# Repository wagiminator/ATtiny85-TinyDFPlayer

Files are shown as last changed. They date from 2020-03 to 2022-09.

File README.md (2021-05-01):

# TinyDFPlayer - MP3-Player based on ATtiny85 and DFPlayerMini
ATtiny controlled and LiPo battery powered MP3-Player using the DFPlayerMini module featuring:
- Micro-SD-card slot
- Battery charging and protection circuit
- Battery level detection
- OLED display
- On/off switch
- Volume control
- Three push buttons to control the player
- Remembers the last track played after switching off (EEPROM)

You can directly connect a 3.7 V Li-Po battery and a 3 W / 4 Ohm speaker to the board.

- Project Video (YouTube): https://youtu.be/QYjr8UXhs8I
- Design Files (EasyEDA): https://easyeda.com/wagiminator/attiny85-tinydfplayer-smd

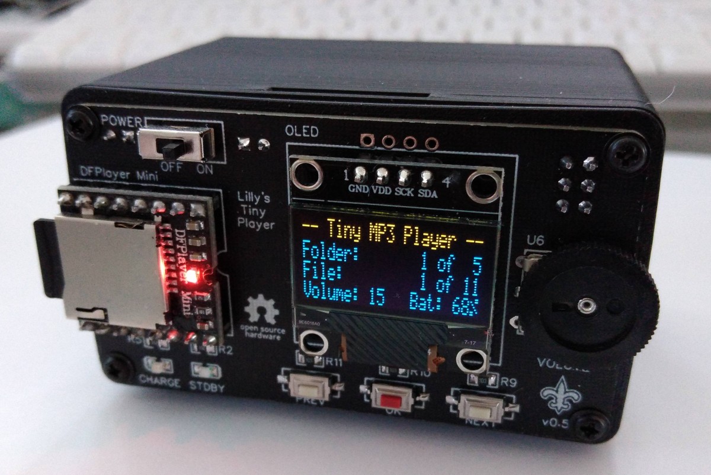
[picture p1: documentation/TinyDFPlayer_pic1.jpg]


# Hardware
## DFPlayer Mini Module
The [DFPLayer Mini module](https://wiki.dfrobot.com/DFPlayer_Mini_SKU_DFR0299) is a serial MP3 module that offers the perfect built-in MP3 hardware decoding. It supports TF cards with FAT16 and FAT32 file systems. Music playback as well as other functions can be controlled by simple serial commands without cumbersome software implementation. The main features of the module are easy to use, stable and reliable functions.

## Battery Charger
For battery charging the [TP4056](https://datasheet.lcsc.com/szlcsc/1904031009_TPOWER-TP4056_C382139.pdf) is used. The TP4056 is a complete constant-current/constant-voltage linear charger for single cell lithium-ion batteries. The charge voltage is fixed at 4.2V and the charge current (max 1000mA) can be programmed externally with a single resistor (R6). The TP4056 automatically terminates the charge cycle when the charge current drops to 1/10th the programmed value after the final float voltage is reached. Other features include current monitor, under voltage lockout and automatic recharge. Charging is done via the built-in [Micro USB connector](https://aliexpress.com/wholesale?SearchText=micro+usb+2pin+dip).

## Battery Protection
For the battery protection (overcharge, overdischarge, overcurrent and short circuit protection) the [DW01A](https://datasheet.lcsc.com/szlcsc/1901091236_PUOLOP-DW01A_C351410.pdf) is used in combination with an [FS8205](https://datasheet.lcsc.com/szlcsc/Fortune-Semicon-FS8205_C32254.pdf) dual MOSFET. The DW01A is constantly measuring the voltage across the battery and the current flowing in (when charging) or coming out (when discharging). If something goes wrong it takes the battery out of the circuit by closing the MOSFET which acts like a switch between the negative side of the battery (B-) and ground. The overcurrent protection works by comparing the voltage drop across the MOSFET with the internal 150mV reference of the DW01A. As the RDS(on) of one FS8205 is around 2x25mOhm, the DW01A will close the MOSFET at 150mV/50mOhm = 3A.

## User Interface
The user interface utilizes three buttons, a wheel potentiometer and a [128x64 pixels OLED display](http://aliexpress.com/wholesale?SearchText=128+64+0.96+oled+new+4pin). An [ATtiny85](https://ww1.microchip.com/downloads/en/DeviceDoc/Atmel-2586-AVR-8-bit-Microcontroller-ATtiny25-ATtiny45-ATtiny85_Datasheet.pdf) microcontroller brings it all together.

# Building Instructions
## Calibrating ATtiny85's Internal Oscillator
Error-free serial communication with the DFPlayer module requires precise timing. Usually the internal oscillator of the ATtiny85 used for this is sufficiently accurate (at least I haven't had any problems so far). However, the serial communication may not work due to an imprecise oscillator. It is therefore recommended to calibrate it manually. There are numerous instructions on how to do this on the [Internet](http://ernstc.dk/arduino/tinytuner.html). Alternatively, the [TinyICOC](https://github.com/wagiminator/ATtiny84-TinyICOC) or the [TinyCalibrator](https://github.com/wagiminator/ATtiny84-TinyCalibrator) can be used for this.

## Building the TinyDFPlayer
Solder all of the components onto the circuit board. Connect a 3.7 V Li-Po battery and a 3 W / 4 Ohm speaker to the corresponding pin headers.

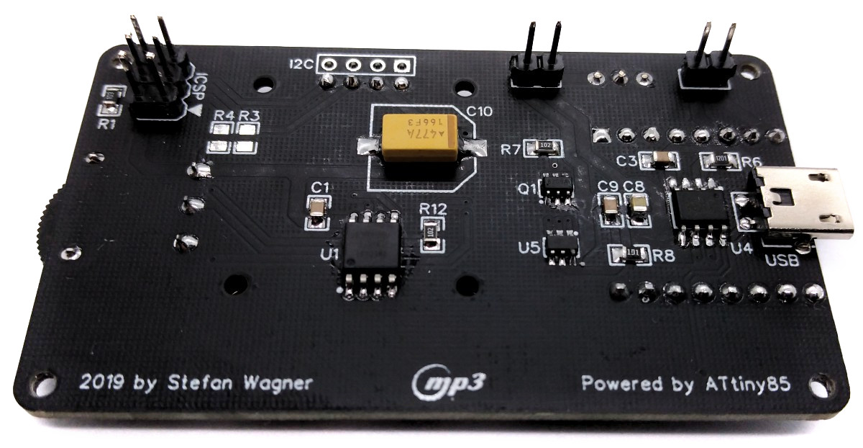
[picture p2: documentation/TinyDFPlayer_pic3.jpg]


If you want to use the 3D-printed case, first install a [70 * 40 mm speaker](https://aliexpress.com/wholesale?SearchText=speaker+4070) in the lower part of the housing and screw it in with 2.3 * 5 mm self-tapping screws. Place an approx. 1 cm thick piece of foam behind the speaker, which fits tightly against the outer walls of the housing. This improves the sound quality significantly and separates the battery from the speaker. Then place the battery. Click the upper part of the housing on the lower part and screw on the TinyDFPlayer Board with 2.3 * 5 mm self-tapping screws. Glue four rubber feet to the underside of the player.

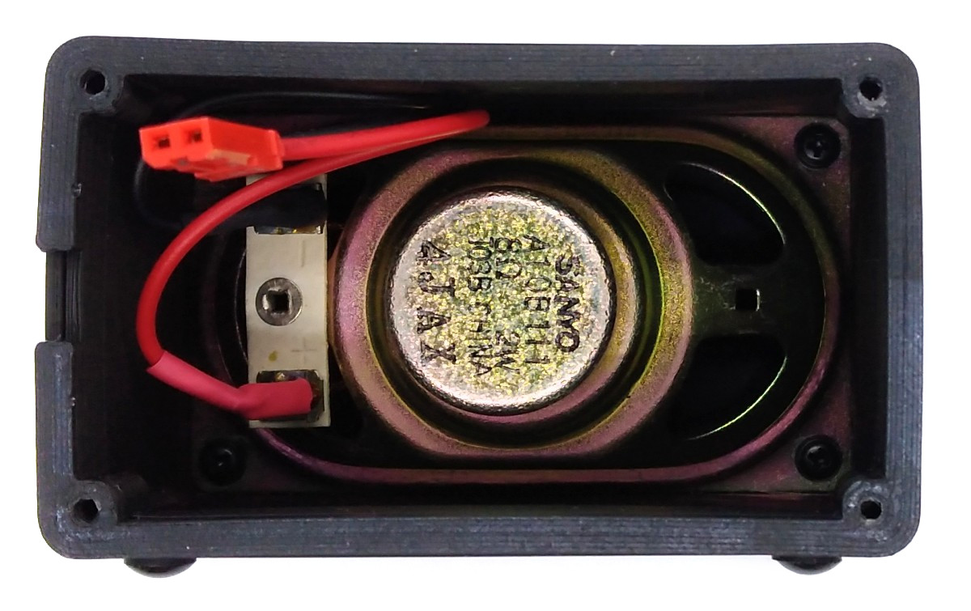
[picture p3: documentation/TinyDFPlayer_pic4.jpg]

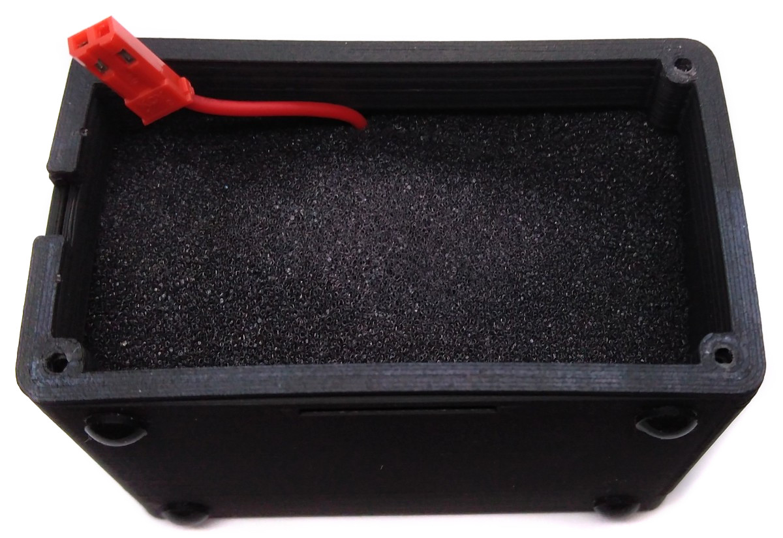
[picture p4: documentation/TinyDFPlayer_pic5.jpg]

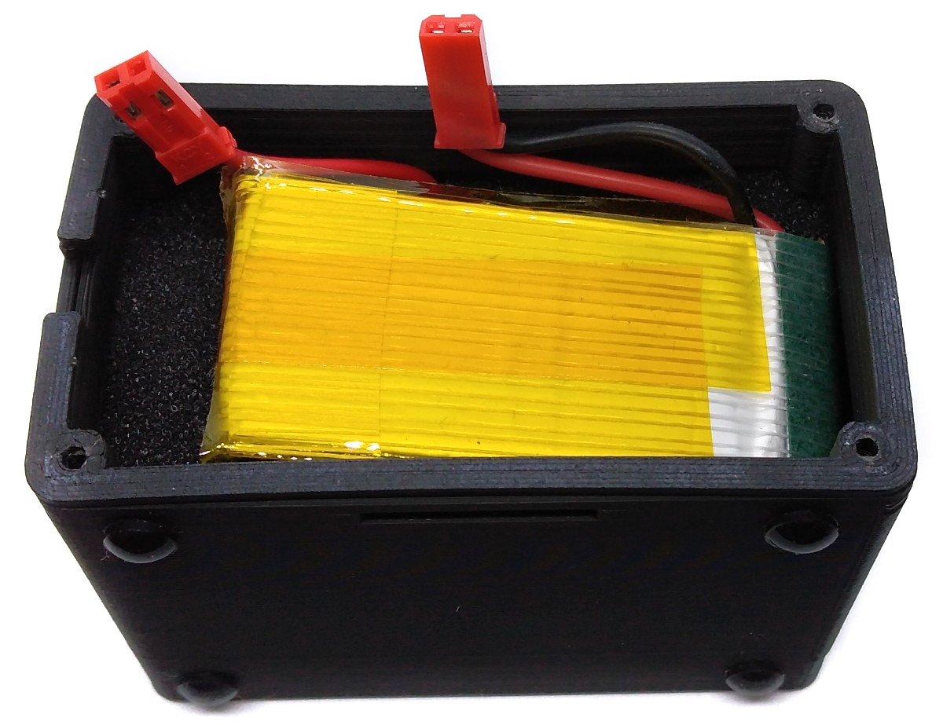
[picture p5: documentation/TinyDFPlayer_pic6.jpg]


## Compiling and Uploading the Software
### If using the Arduino IDE
- Make sure you have installed the following core and libraries: 
  - [ATtinyCore](https://github.com/SpenceKonde/ATTinyCore)
  - [TinyI2CMaster](https://github.com/technoblogy/tiny-i2c)
  - [Tiny4kOLED](https://github.com/datacute/Tiny4kOLED)
  - [DFRobotDFPlayerMini](https://github.com/DFRobot/DFRobotDFPlayerMini)
- Go to **Tools -> Board -> ATtinyCore** and select **ATtiny25/45/85 (No bootloader)**.
- Go to **Tools** and choose the following board options:
  - **Chip:**           ATtiny85
  - **Clock:**          8 MHz (internal)
  - Leave the rest at the default settings
- Connect your programmer to your PC and to the ICSP header of the device.
- Go to **Tools -> Programmer** and select your ISP programmer (e.g. [USBasp](https://aliexpress.com/wholesale?SearchText=usbasp)).
- Go to **Tools -> Burn Bootloader** to burn the fuses.
- Open TinyDFPlayer sketch and click **Upload**.

### If using the precompiled hex-file
- Make sure you have installed [avrdude](https://learn.adafruit.com/usbtinyisp/avrdude).
- Connect your programmer to your PC and to the ICSP header of the device.
- Open a terminal.
- Navigate to the folder with the hex-file.
- Execute the following command (if necessary replace "usbasp" with the programmer you use):
  ```
  avrdude -c usbasp -p t85 -U lfuse:w:0xe2:m -U hfuse:w:0xd7:m -U efuse:w:0xff:m -U flash:w:tinyDFPlayer_v1.2.hex
  ```

# Operating Instructions
## Preparing the SD-Card
Micro SD cards (TF cards) with a maximum of 32 GB are supported. The card should be formatted in the FAT32 file system. The firmware is written for the folder-play function of the DFPlayer. This means you have to create folders named 01, 02, 03, ... in the  SD card root and inside the folders you have to name the audio files 001.mp3, 002.mp3, ... The maximum number of folders is 99 and the maximum number of files per folder is 255. Don't leave gaps in the folders or file numbers. After the three-digit number of the MP3 files, the title name can be added for better identification, e.g. "003_MySong.mp3". Note that the title names cannot be read out and transmitted by the MiniDFPlayer module, so unfortunately it is not possible to display the title names.

There must not be any unnecessary files on the SD card, such as those stored there by MacOS (e.g. Spotlight). Better take Linux or Windows to write to the SD card. Under MacOS you can try to clean up with the following command:

```
$ dot_clean /Volumes/SD-Card
```

Insert the SD card into the corresponding slot of the DFPlayer Mini module.

## Operating the TinyDFPlayer
The device is switched on with the power switch. The two outer buttons are used to switch files and folders. The middle button is used to switch between pause and play. The wheel potentiometer is for choosing the volume. All necessary information is displayed on the OLED. To charge the battery, connect a 5V power supply via the micro USB port.

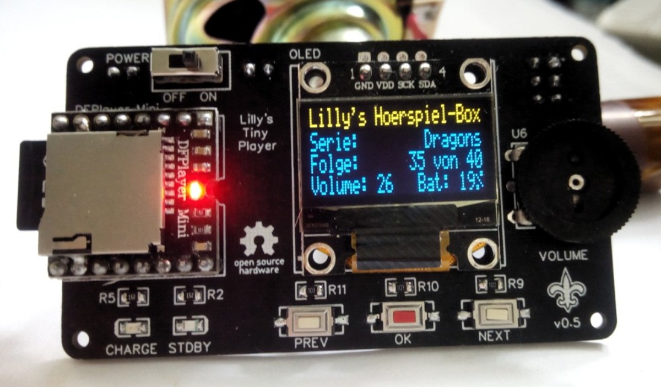
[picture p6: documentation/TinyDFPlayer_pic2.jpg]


# License


This work is licensed under Creative Commons Attribution-ShareAlike 3.0 Unported License. 
(http://creativecommons.org/licenses/by-sa/3.0/)

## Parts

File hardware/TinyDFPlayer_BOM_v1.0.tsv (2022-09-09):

ID | Name | Designator | Footprint | Quantity | Manufacturer Part | Manufacturer | Supplier | Supplier Part
1 | Header | SPK | HDR-1X2/2.54 | 1 | 2.54-1*2PFemale | BOOMELE | LCSC | C49661
2 | Connector | BAT | HDR-1X2/2.54 | 1 | 2.54-1*2PFemale | BOOMELE | LCSC | C49661
3 | DFPlayer | U2 | DFPLAYER_MINI | 1 | ?
4 | 100n | C1,C9,C3 | 805 | 3 | CC0805KRX7R9BB104 | YAGEO | LCSC | C49678
5 | 10u | C8 | 805 | 1 | CL21A106KAYNNNE | SAMSUNG | LCSC | C15850
6 | I2C | I2C | HDR-4X1/2.54 | 1 | Header-Female-2.54_1x4 | ReliaPro | LCSC | C124413
7 | 470uF | C10 | CAP-SMD_D10.0-L10.3-W10.3-H10.2 | 1 | EEE1CA471P | PANASONIC | LCSC | C336217
8 | OLED | OLED | OLED | 1 | ?
9 | ATTINY85-20SU | U1 | SOIC-8_208MIL | 1 | ATTINY85-20SU | MICROCHIP | LCSC | C89852
10 | USB PWR Connector | USB | USB PWR CONNECTOR | 1 | KH-MICRO-SMT.J-2P | Shenzhen Kinghelm Elec | LCSC | C2688799
11 | Slide Switch | POWER | SLIDE SWITCH DPDT 1P2T JB | 1 | New SchematicLib
12 | FS8205 | Q1 | SOT-23-6 | 1 | FS8205 | FORTUNE | LCSC | C32254
13 | ICSP-6 | ICSP | ICSP-6 | 1 | C65114 | BOOMELE | LCSC | C65114
14 | 3x6x2.5 | PREV,NEXT,OK | KEY-3.0*6.0 | 3 | 3x6x2.5Red head high temperature | ReliaPro | LCSC | C46491
15 | 1k | R12,R7 | 805 | 2 | 0805W8F1001T5E | UniOhm | LCSC | C17513
16 | 10k | R11,R10,R1,R9 | 805 | 4 | 0805W8F1002T5E | UniOhm | LCSC | C17414
17 | 4k7 | R4,R3 | 805 | 2 | 0805W8F4701T5E | UniOhm | LCSC | C17673
18 | 1k2 | R6 | 805 | 1 | 0805W8F1201T5E | UniOhm | LCSC | C17379
19 | 1k5 | R5,R2 | 805 | 2 | 0805W8F1501T5E | UniOhm | LCSC | C4310
20 | 100 | R8 | 805 | 1 | 0805W8F1000T5E | UniOhm | LCSC | C17408
21 | DW01A | U5 | SOT-23-6 | 1 | DW01A | FM | LCSC | C85680
22 | 47u | C2 | 1206 | 1 | 1206F476M160NT | FH | LCSC | C30300
23 | Red | L2 | LED-0805 | 1 | 17-21VRD/TR8 | Everlight Elec | LCSC | C264415
24 | Blue | L1 | LED-0805 | 1 | E6C0805QBAC1UDA | EKINGLUX | LCSC | C375453
25 | TP4056 | U4 | SOP-8_EP_150MIL | 1 | TP4056 | TOPPOWER | LCSC | C16581
26 | B103 3 pin | U6 | B103 3 PIN | 1 | ?

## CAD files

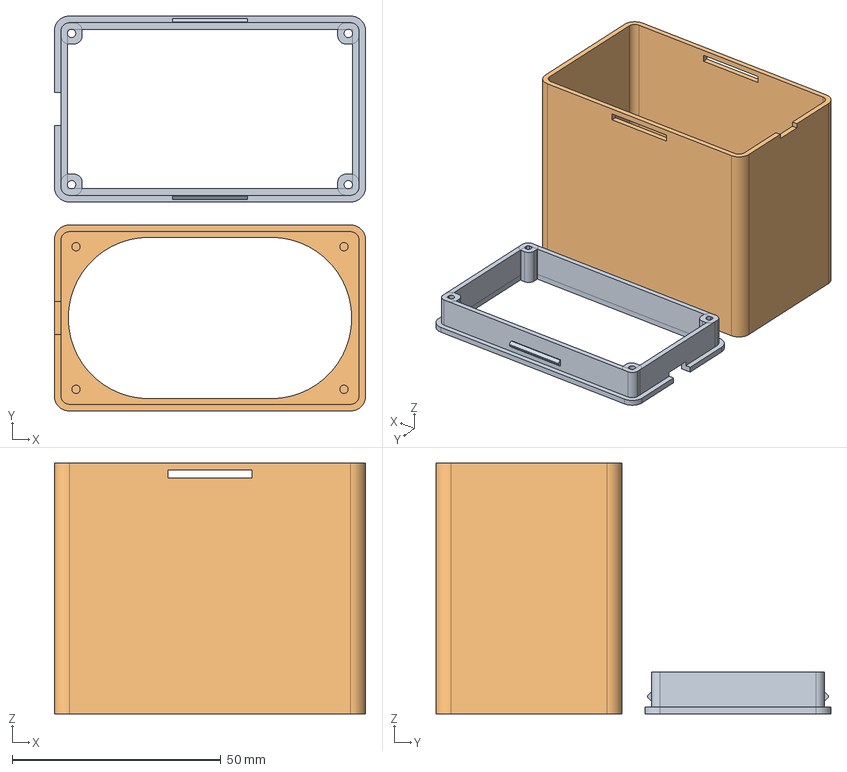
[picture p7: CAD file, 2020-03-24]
3dprint/TinyDFplayer2.fcstd
74.5 x 94.5 x 60.0 mm
Boardhalter
Speakerhalter

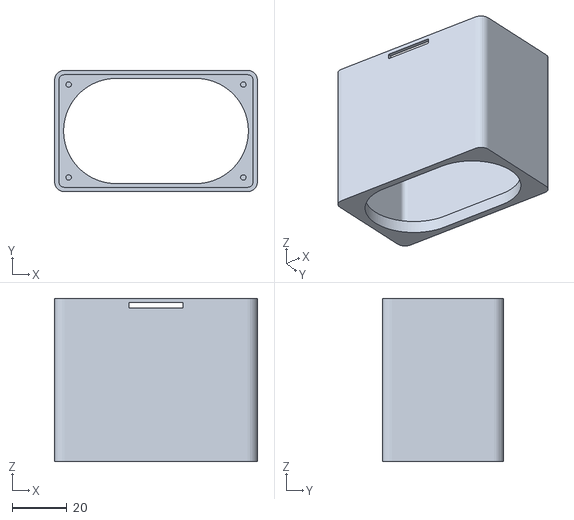
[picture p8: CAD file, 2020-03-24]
3dprint/TinyDFPlayer_SpeakerHolder_v2.stl
74.5 x 44.5 x 60.0

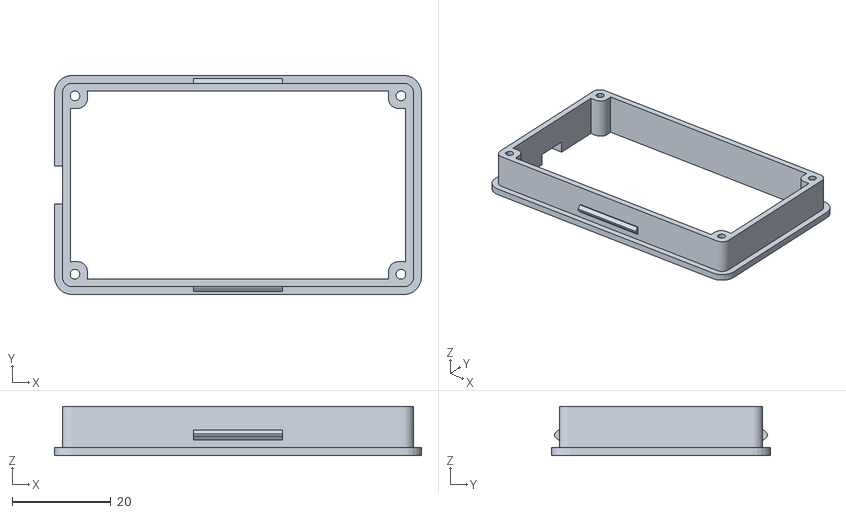
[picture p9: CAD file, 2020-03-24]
3dprint/TinyDFPlayer_BoardHolder.stl
74.5 x 44.5 x 10.0

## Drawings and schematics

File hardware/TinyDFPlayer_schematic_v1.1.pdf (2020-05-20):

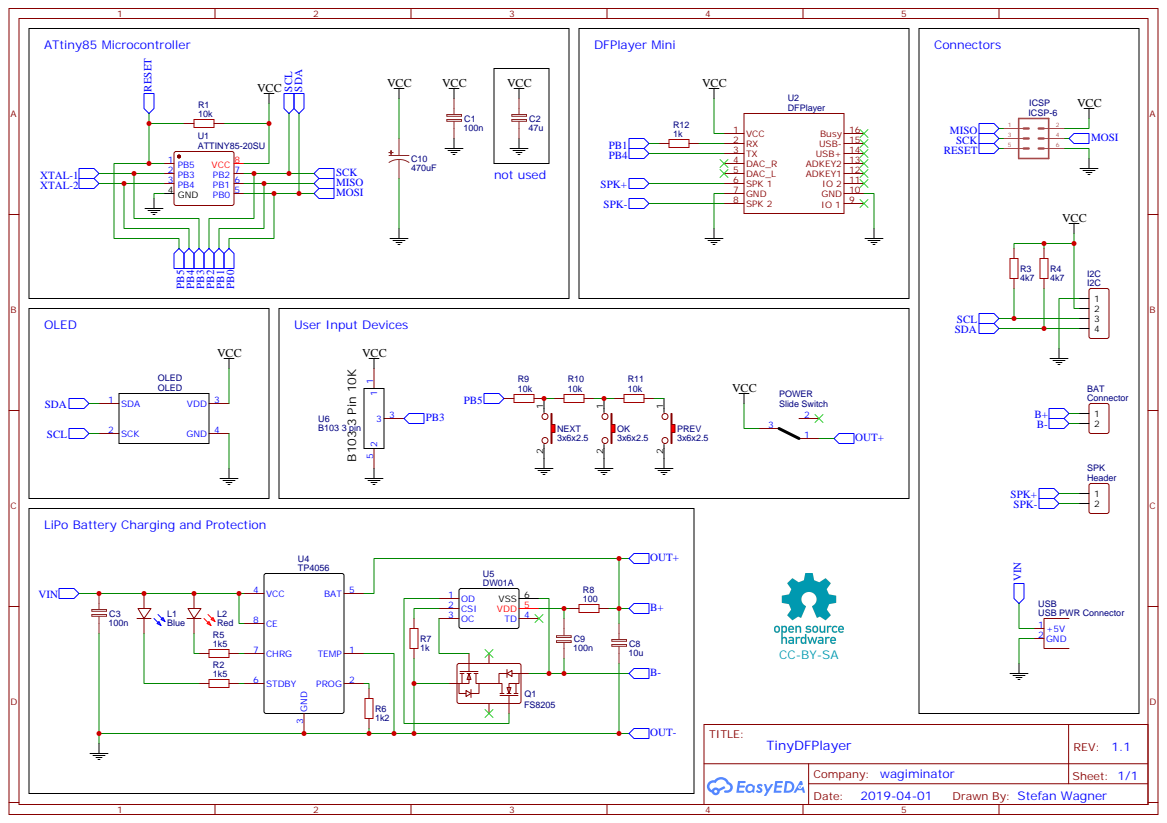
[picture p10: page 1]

GND 10 IO 2 11 ADKEY1 12 ADKEY2 13 USB+ 14 USB- 15 Busy 16

LiPo Battery Charging and Protection

Drawn By: Stefan Wagner

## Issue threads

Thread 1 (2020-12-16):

ATTiny fails to start DFPlayer

8BitMark, 2020-12-16:
Which library are you using for DFPlayer?  Every time I try to use the ATTiny85 to control the DFPlayer I just get a clicking sound, DFPlayer fails to wake and ATTiny seems to get stuck at this point

if (!tinyPlayer.begin(tinySerial)) {

everything works fine if I control the DFPlayer using same code (but different RX TX pins) on an Arduino Uno

wagiminator, 2020-12-16:
I'm using this library: https://github.com/DFRobot/DFRobotDFPlayerMini. First make sure, your ATtiny is running at 8 MHz internal (set the correct fuses by "Burning bootloader" in the Arduino IDE). If it's still not working, please try a different library: https://github.com/PowerBroker2/DFPlayerMini_Fast (you may have to make a few adjustments to the code). A user had the same problem before and solved it with the new library. It seems that different chips are built into the DFplayer module and not all of them work with the old library. I haven't had any problems with my modules yet.

wagiminator, 2020-12-16:
I attached 2 hex-files to the binary folder which worked for the user. Unfortunately I don't have the source code. However, you can test whether the player works with it.

8BitMark, 2020-12-18:
Thanks for your help, seems i was running a different version of the library.  So that plus a delay(500) before the begin statement solved it.

The version on the prototype board then worked fine but the bread board version didn't.  Bread board version only worked reliably if volume was set to 15 or less.  Otherwise it played first second or two then turned itself off.  Higher the volume, the less it played before shutting down.

wagiminator, 2020-12-19:
Interesting, the delay will be built into the next software version as standard. Did you use a capacitor with at least 470uF near the DFPlayer on your breadboard version?

8BitMark, 2020-12-21:
I started with 100uf and then tried 470uf after your email as I'd missed
that on your circuit diagram.  With the 470uf the DFPLAYER won't start.
Have to short the play next track pin to get it to play then same
behaviour, louder the volume the shorter it plays before the dfplayer light
goes out and the clicking sound starts.

On prototype board it's fine.  Could the breadboad quality be an issue?

BTW, thanks for responding to my email earlier emails and the help and
guidance you provided, very much appreciated.

Thank you

On Sat, 19 Dec 2020 at 19:28, Stefan Wagner <notifications@github.com>
wrote:

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
--

Regards
Mark

*Mark Warner*
<http://goog_1458174335>
www.mark-warner.co.uk
www.skatermark.co.uk

wagiminator, 2020-12-22:
I tested the circuit on a breadboard and it worked. Since the problem only occurs at higher volume levels, I would tap power issues. Do you use a different power supply than with the prototype board?

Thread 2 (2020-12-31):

Bill of materials

S-Snowball, 2020-12-31:
Hi,

do you have a f BOM with source where you can buy? I ordered a small OLED from Aliexpress, but this is not working with your code. I think the best is to use the same sources to order some.

wagiminator, 2020-12-31:
Hi,
I also got my OLEDs from aliexpress (https://aliexpress.com/item/32957309383.html). Can you give me a more detailed description of the problem?

S-Snowball, 2020-12-31:
Only the backlight is working. No text on the Display. And mp3 Player is also working, but without the Display.

I have the smaller 0.49 Display, Maybe is this the problem.

I order now the 0.96 Display.

Thanks a lot for the link

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

wagiminator, 2021-01-01:
Then it will probably be the OLED. Presumably it has a different controller chip.

S-Snowball, 2021-01-07:
As I am currently waiting for the display to be delivered, I have been giving it some more thought and have come up with 2 questions.

1. is there a random function? That from all folders a random MP3 is played?

2. can it display the song name?

wagiminator, 2021-01-07:
1. Not in the current software version. Feel free to add such a feature, it shouldn't be too difficult.
2. This is not possible because the DFPlayer module only understands folder and file numbers. You would have to include a table in the code that assigns a song name to the file number. However, this is much too cumbersome and you would have to change the code every time you change the content of the SD card.

S-Snowball, 2021-01-07:
I will try
do you have the circuit diagram only at EasyEDA?
I would like to add something, but I have not yet worked with EasyEDA and find it a bit confusing in the first moment. Especially in the area of routing

wagiminator, 2021-01-07:
Sorry, I only use EasyEDA.

S-Snowball, 2021-02-25:
Hi,
unfortunately I didn't get to it before....

Could you possibly look at the circuit diagram, whether I have drawn correctly?

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

When Im finish, I will share eagle board and circuit with adjusted code.

wagiminator, 2021-02-26:
You forgot the 10k pull-up resistor on PB5. Without this resistor, a RESET is carried out each time a button is pressed.

S-Snowball, 2021-03-19:
Hi,

the first board is soldered. Now when I turn on the MP3 player, I get this error.

```
!!!     ERROR     !!!
Check SD-Card andstart again !
```

My SD card has 2 GB and is formatted to FAT32. I also tested it with a 4GB card, but the same error.

Do you have any idea about this?
Is it possible that the DFPlayer mini itself is broken?

wagiminator, 2021-03-19:
Hi, first make sure that your ATtiny is running at 8 MHz internal (set the correct fuses by "Burning bootloader" in the Arduino IDE) and that you are using the latest software version. If it's still not working, take a look at the other opened issue. It seems that there are different versions of the DFPlayer module. A different DFPlayer library might help.

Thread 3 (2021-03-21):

Cant use DFPlayer

bixicy, 2021-03-21:
Hi,

I have also the problem here: https://github.com/wagiminator/ATtiny85-TinyDFPlayer/issues/2

Without Attiny I can use DFPlayer. But when I connect to the Attiny its not possible to play mp3 files.

I cheked, ATtiny is running at 8 MHz internal. It's still not working. A tried different DFPlayer library. but I cant the correct one.

Can you help to change from attiny to Arduino pro mini?

I have to change
#include <TinyI2CMaster.h>
#include <Tiny4kOLED.h>

looks like the two librarys are not compatible with the pro mini

wagiminator, 2021-03-22:
Hi,
replace "#include <TinyI2CMaster.h>" with "#include <Wire.h>". The OLED library will then automatically use the other I2C library. You have to connect the OLED to the SDA/SCL pins of the pro mini.

BTW, do you have the possibility to check/calibrate the internal oscillator of the ATtiny? Maybe the oscillator is too far off for the serial communication with the DFPlayer to work. It's hard for me to find the root of problem because all four of my builds work without any problem.

bixicy, 2021-03-24:
Hi,
thank you

I just tested this, but I'm not quite happy with it yet. The sketch is uploaded without error message, but a few things are not working yet.

Battery indicator, buttons, volume

I have commented out the battery indicator for now, that is the last thing I will do.

Are the buttons with 10k each correct? If I calculate correctly, then 10k 0V come out as a value. Or how is the value of each button calculated.

I have just researched this in google,

volt * 5.0 / 1023.0

If I countermeasure the button with the multimeter, then no more voltage comes from the input voltage of 5.04v.

wagiminator, 2021-03-24:
Hi, are you using the Arduino or the ATtiny now? When using the Arduino, of course, you have to make sure that you have implemented the correct pins and the correct ADC port in the code. Don't forget the 10k pullup for the buttons. This forms a voltage divider with the other 10k resistors on the buttons.

VU2ATX, 2022-01-03:
Thanks for the wonderful gadget design, I followed your laid-down instructions and got it working. I faced some issues and have some of them still popping up;
1. The 0.96" OLED in the market have VCC and GND pins swapped so had to remove the 4 pin connector on the OLED module and used wires to connect. My suggestion is; In the next PCB version, it would be better to provide solder jumpers to select accordingly. There is another option to use Schottky bridge chip to power the OLED module, this will avoid any jumpers but one small drawback would be that it would reduce the supply voltage by 0.2V

2.   I am able to compile and upload any of your sketch versions; tinyDFPlayer_v1.0.ino, tinyDFPlayer_v1.1.ino, tinyDFPlayer_v1.2.ino but all of them have similar behavior that the folder count is always displayed 25 whereas on the SD card there are 18 folders (01-18).  Similar is the case with file count.

3.  Via "Previous" button when I am trying to switch folder then at one time it displays like Folder:   26 of 25 or even 29 of 25, it looks like an issue, Pls suggest

4.  In case I want to use Arduino pro mini which is cheaper and I have lots of them then what necessary suggested pin / code changes are required.

5. I tried uploading your compiled "tinyDFPlayer_v1.2.hex" using USBasp, following your instructions;
avrdude -c usbasp -p t85 -U lfuse:w:0xe2:m -U hfuse:w:0xd7:m -U efuse:w:0xff:m -U flash:w:tinyDFPlayer_v1.2.hex

But looks like it required your  tinyDFPlayer_v1.2.eep file for the EEPROM, pls share the same.

Thanks in advance

wagiminator, 2022-01-09:
Hi,
1. All of my OLEDs have the pinout I used on the board, but if I should ever make a new version of the board, then I'll think about it.
2 + 3. Strange. I have no idea right now. I have several of these boxes in use, but none of them showed any issue.
4. Connect the volume pot to any analog pin, use a dedicated pin for each button, connect the oled to the standard I²C pins and the DFPlayer to any free pins and use the software serial library to leave RX/TX free for uploading code. Of course you have to make some changes in the code.
5. This is even more strange. You don't need any eep file.

VU2ATX, 2022-01-14:
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

Stephen, than you so much for the reply.

_> 4. Connect the volume pot to any analog pin, use a dedicated pin for each button, connect the oled to the standard I²C pins and the DFPlayer to any free pins and use the software serial library to leave RX/TX free for uploading code. Of course you have to make some changes in the code._
Thank you, will try

_> 5. This is even more strange. You don't need any eep file._
If possible pls read the EEPROM of your board and share.

wagiminator, 2022-01-24:
Since I only flashed a blank attiny myself, you can pull the eep from a blank attiny yourself:
avrdude -c usbasp -p t85 -U eeprom:r:tinyDFPlayer_v1.2.eep:i
But for me that still doesn't make any sense, you don't need an eep file, the error must be somewhere else.

VU2ATX, 2022-01-27:
> Since I only flashed a blank attiny myself, you can pull the eep from a blank attiny yourself: avrdude -c usbasp -p t85 -U eeprom:r:tinyDFPlayer_v1.2.eep:i But for me that still doesn't make any sense, you don't need an eep file, the error must be somewhere else.

Thanks for reply, can you please pull eep file from your flashed attiny85, that could resolve my issue.

I have tried what you suggested but no solution from pulling eep from blank attiny85

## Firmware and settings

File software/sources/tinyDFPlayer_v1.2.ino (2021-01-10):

// tinyDFPlayer
//
// MP3-Player using DFPlayer mini, ATtiny85, I2C OLED,
// potentiometer and three buttons.
//
//                                 +-\/-+
// Buttons --------- A0 (D5) PB5  1|    |8  Vcc
// Poti ------------ A3 (D3) PB3  2|    |7  PB2 (D2) A1 ---- OLED (SCK)
// DFPlayer (TX) --- A2 (D4) PB4  3|    |6  PB1 (D1) ---- DFPlayer (RX)
//                           GND  4|    |5  PB0 (D0) ------- OLED (SDA)
//                                 +----+
//
// RESET pin is used as a weak analog input for the buttons. You don't
// need to disable the RESET pin as the voltage won't go below 40% of Vcc.
//
// Core:    ATtinyCore (https://github.com/SpenceKonde/ATTinyCore)
// Board:   ATtiny25/45/85 (No bootloader)
// Chip:    ATtiny85
// Clock:   8 MHz (internal)
// Leave the rest on default settings. Don't forget to "Burn bootloader" !
//
// 2019 by Stefan Wagner
// Project Files (EasyEDA): https://easyeda.com/wagiminator
// Project Files (Github):  https://github.com/wagiminator
// License: http://creativecommons.org/licenses/by-sa/3.0/


// Libraries
#include <SoftwareSerial.h>             // for serial communication
#include <TinyI2CMaster.h>              // https://github.com/technoblogy/tiny-i2c
#include <Tiny4kOLED.h>                 // https://github.com/datacute/Tiny4kOLED
#include <DFRobotDFPlayerMini.h>        // https://github.com/DFRobot/DFRobotDFPlayerMini
#include <EEPROM.h>                     // for storing last file/folder in EEPROM
#include <avr/pgmspace.h>               // for data stored in program memory
#include <avr/sleep.h>                  // for sleep functions
#include <avr/interrupt.h>              // for interrupts
#include <avr/power.h>                  // for power saving functions
#include <avr/wdt.h>                    // for watch dog timer

// Pin assignments
#define TXPIN       1                   // connect to RX on DFPlayer via 1k resistor
#define RXPIN       4                   // connect to TX on DFPlayer
#define POTIPIN     A3                  // connect to wiper of potentiometer
#define BUTTONS     A0                  // connect to buttons, make shure voltage
                                        // don't fall below 40% of Vcc
// EEPROM usage
#define USE_EEPROM  true                // set false if you don't want to use EEPROM

// Analog values of the buttons
#define NEXT        552
#define OK          712
#define PREV        790

// OLED contrast levels
#define BRIGHT      127
#define DIMM        50

// Text strings stored in program memory
const char Header[]  PROGMEM = "-( Tiny MP3 Player )-";
const char Error1[]  PROGMEM = "!!!     ERROR     !!!";
const char Error2[]  PROGMEM = "Check SD-Card and";
const char Error3[]  PROGMEM = "start again !";
const char Empty1[]  PROGMEM = "!!! Battery empty !!!";
const char Empty2[]  PROGMEM = "Please recharge !";

// Variables
uint8_t filecounts;                     // total number of files in current folder
uint8_t foldercounts;                   // total number of folders on sd-card

uint8_t batlevel;                       // current battery level in percent
uint8_t volume = 20;                    // current volume (0 .. 30)
uint8_t folder = 1;                     // current sd-card folder
uint8_t file   = 1;                     // curent file in current folder
boolean pause  = false;                 // true when player is paused

uint16_t batcounter;                    // used to time battery level readings
uint16_t lastpoti;                      // last value of potentiometer

// Initializations
SoftwareSerial tinySerial(RXPIN,TXPIN); // init serial communication
DFRobotDFPlayerMini tinyPlayer;         // init DFPlayerMini

// -----------------------------------------------------------------------------
// Main Function
// -----------------------------------------------------------------------------

// Setup
void setup() {
  // reset watchdog timer
  resetWatchdog ();                     // do this first in case WDT fires

  // setup and disable ADC for energy saving
  ADCSRA  = bit (ADPS1) | bit (ADPS2);  // set ADC clock prescaler to 64
  ADCSRA |= bit (ADIE);                 // enable ADC interrupt
  interrupts ();                        // enable global interrupts
  power_adc_disable();                  // turn off ADC

  // init pins
  pinMode (POTIPIN, INPUT);
  pinMode (BUTTONS, INPUT);
  
  // prepare and start OLED
  oled.begin();
  oled.setFont(FONT6X8);
  oled.setContrast(BRIGHT);
  oled.clear();
  oled.on();
  oled.switchRenderFrame();

  // write start screen
  oled.clear();
  oled.setCursor(0, 0);
  printP(Header);
  oled.setCursor(0, 1);
  oled.print(F("Starting..."));
  oled.switchFrame();

  // start communication with DFPlayer mini
  tinySerial.begin(9600);
  delay(500);
  if (!tinyPlayer.begin(tinySerial)) {
    oled.clear();
    oled.setCursor(0, 0);
    printP(Error1);
    oled.setCursor(0, 2);
    printP(Error2);
    oled.setCursor(0, 3);
    printP(Error3);
    oled.switchFrame();
    oled.setContrast(DIMM);
    tinyPlayer.sleep();
    while(true) sleep();
  }

  // check battery level
  checkBatLevel();

  // read EEPROM
  if (USE_EEPROM) {
    if (EEPROM.read(0) == 55) {
      file   = EEPROM.read(1);
      folder = EEPROM.read(2);
    }
    else EEPROM.write(0, 55);
  }

  // start the player
  tinyPlayer.setTimeOut(500);
  tinyPlayer.volume(volume);
  foldercounts = tinyPlayer.readFolderCounts();
  filecounts   = tinyPlayer.readFileCountsInFolder(folder);
  startFolderPlay();
}

// Loop
void loop() {

  // check player status
  if (tinyPlayer.available()) {
    uint8_t type = tinyPlayer.readType();
    int value    = tinyPlayer.read();

    if (type == DFPlayerPlayFinished) {
      file++;
      startFolderPlay();
    }
  }
  
  // get, debounce and set volume
  uint16_t getpoti = denoiseAnalog(POTIPIN);
  if ( (getpoti < (lastpoti - 8)) || (getpoti > (lastpoti + 8)) ) lastpoti = getpoti; 
  uint8_t getvol = lastpoti / 34;
  if (getvol != volume) {
    volume = getvol;
    tinyPlayer.volume(volume);
    updateOLED();
  }

  // check buttons
  uint16_t buttons = getAnalog(BUTTONS);
  if (buttons < 1000) {
    
    if ( (buttons < (PREV + 20)) && (buttons > (PREV - 20)) ) {
      if (folder < foldercounts) folder++; else folder = 1;
      filecounts = tinyPlayer.readFileCountsInFolder(folder);
      file = 1;     
      startFolderPlay();
    }

    if ( (buttons < (NEXT + 20)) && (buttons > (NEXT - 20)) ) {
      file++;
      startFolderPlay();
    }

    if ( (buttons < (OK + 20)) && (buttons > (OK - 20)) ) {
      pause = !pause;
      if (pause) tinyPlayer.pause();
      else tinyPlayer.start();
      updateOLED();
    }

    while(getAnalog(BUTTONS) < 1000);
  }

  // check battery level every now and then
  if ((--batcounter) == 0) checkBatLevel();

  // sleep for a short time to save some energy
  sleep();
}

// -----------------------------------------------------------------------------
// DFPlayer Mini Functions
// -----------------------------------------------------------------------------

// starts to play the actual file in the actual folder
void startFolderPlay() {
  if (folder > foldercounts) {
    folder = 1;
    file   = 1;
    filecounts = tinyPlayer.readFileCountsInFolder(folder);
  }
  if (file > filecounts) file = 1;

  tinyPlayer.playFolder(folder, file);
  pause = false;
  updateOLED();

  if (USE_EEPROM) {
    EEPROM.update(1, file);
    EEPROM.update(2, folder);
  }
}

// -----------------------------------------------------------------------------
// Display Functions
// -----------------------------------------------------------------------------

// prints the actual values on the OLED
void updateOLED() {
  oled.clear();
  oled.setCursor(0, 0);
  printP(Header);
  oled.setCursor(0, 1);
  oled.print(F("Folder:    "));
  printDigits(folder);
  oled.print(F(" of "));
  printDigits(foldercounts);
  oled.setCursor(0, 2);
  oled.print(F("File:      "));
  printDigits(file);
  oled.print(F(" of "));
  printDigits(filecounts);
  oled.setCursor(0, 3);
  printBatLevel();
  oled.setCursor(66, 3);
  if (pause) oled.print(F(" < Pause >"));
  else {
    oled.print(F("Volume:"));
    printDigits(volume);
  }
  oled.switchFrame();
}

// prints a string from progmem on the OLED
void printP(const char* p) {
  char ch = pgm_read_byte(p);
  while (ch) {
    oled.print(ch);
    ch = pgm_read_byte(++p);
  }
}

// converts number to 3-digits and prints it on OLED
void printDigits(uint8_t digits) {
  if(digits < 100) oled.print(F(" "));
  if(digits <  10) oled.print(F(" "));
  oled.print(digits);
}

// prints battery charging level on OLED
void printBatLevel() {
  oled.print(F("Bat:"));
  printDigits(batlevel);
  oled.print(F("%"));
}


// checks and updates battery level; stops player if bat is empty
void checkBatLevel() {
  batlevel = getBatLevel();
  
  // if battery is empty wait for recharging
  if (batlevel == 0) {
    oled.setContrast(DIMM);
    oled.clear();
    oled.setCursor(0, 0);
    printP(Empty1);
    oled.setCursor(15, 2);
    printP(Empty2);
    oled.switchFrame();
    if (!pause) tinyPlayer.pause();
    while(getBatLevel() < 10) sleep();
    oled.setContrast(BRIGHT);
    batlevel = getBatLevel();
    if (!pause) tinyPlayer.start();
  }
  
  updateOLED();
  batcounter = 600;
}

// -----------------------------------------------------------------------------
// ADC Functions
// -----------------------------------------------------------------------------
  
// take an ADC reading in sleep mode
uint16_t getAnalog (byte port) {
  power_adc_enable();                   // power on ADC
  ADCSRA |= bit (ADEN) | bit (ADIF);    // enable ADC, turn off any pending interrupt
  if (port >= A0) port -= A0;           // set port and
  ADMUX = (port & 0x07);                // reference to AVcc   
  set_sleep_mode (SLEEP_MODE_ADC);      // sleep during sample for noise reduction
  sleep_mode();                         // go to sleep while taking ADC sample
  while (bitRead(ADCSRA, ADSC));        // make sure sampling is completed
  uint16_t result = ADC;                // read ADC sample result
  bitClear (ADCSRA, ADEN);              // disable ADC
  power_adc_disable();                  // and save some energy
  return result;                        // return value
}

// average several ADC readings to denoise
uint16_t denoiseAnalog (byte port) {
  uint16_t result = 0;
  power_adc_enable();                   // power on ADC
  ADCSRA |= bit (ADEN) | bit (ADIF);    // enable ADC, turn off any pending interrupt
  if (port >= A0) port -= A0;           // set port and
  ADMUX = (port & 0x07);                // reference to AVcc   
  set_sleep_mode (SLEEP_MODE_ADC);      // sleep during sample for noise reduction
  for (uint8_t i=0; i<8; i++) {         // get 8 readings
    sleep_mode();                       // go to sleep while taking ADC sample
    while (bitRead(ADCSRA, ADSC));      // make sure sampling is completed
    result += ADC;                      // add them up
  }
  bitClear (ADCSRA, ADEN);              // disable ADC
  power_adc_disable();                  // and save some energy
  return (result >> 3);                 // devide by 8 and return value
}

// get the battery charging level in percent by reading 1.1V reference against AVcc
uint8_t getBatLevel() {
  power_adc_enable();                   // power on ADC
  ADCSRA |= bit (ADEN) | bit (ADIF);    // enable ADC, turn off any pending interrupt
  ADMUX = bit (MUX3) | bit (MUX2);      // set Vcc measurement against 1.1V reference
  delay(2);                             // wait for Vref to settle
  set_sleep_mode (SLEEP_MODE_ADC);      // sleep during sample for noise reduction
  sleep_mode();                         // go to sleep while taking ADC sample
  while (bitRead(ADCSRA, ADSC));        // make sure sampling is completed
  uint32_t vcc = ADC;                   // read ADC sample result
  bitClear (ADCSRA, ADEN);              // disable ADC
  power_adc_disable();                  // and save some energy
  vcc = 1125300L / vcc;                 // calculate Vcc in mV; 1125300 = 1.1*1023*1000
  vcc = constrain(vcc, 3200, 4100);     // 3200mV - bat empty, 4100mV - bat fully charged
  uint8_t result = (vcc - 3200) / 9;    // calculate bat level in percent
  return result;                        // return percentage value
}

// -----------------------------------------------------------------------------
// Sleep Functions and Interrupt Service Routines
// -----------------------------------------------------------------------------

// go to sleep in order to save energy, wake up again by watchdog timer
void sleep() {
  set_sleep_mode (SLEEP_MODE_PWR_DOWN); // set sleep mode to power down
  bitSet (GIFR, PCIF);                  // clear any outstanding interrupts
  power_all_disable ();                 // power off ADC, Timer 0 and 1, serial interface
  noInterrupts ();                      // timed sequence coming up
  resetWatchdog ();                     // get watchdog ready
  sleep_enable ();                      // ready to sleep
  interrupts ();                        // interrupts are required now
  sleep_cpu ();                         // sleep              
  sleep_disable ();                     // precaution
  power_all_enable ();                  // power everything back on
  power_adc_disable();                  // except ADC
}

// reset watchdog timer
void resetWatchdog () {
  MCUSR = 0;                            // clear various "reset" flags
  WDTCR = bit (WDCE) | bit (WDE) | bit (WDIF);  // allow changes, disable reset, clear existing interrupt
  WDTCR = bit (WDIE) | bit (WDP1);      // set interval to 64 milliseconds
  wdt_reset();                          // pat the dog
}

// watchdog interrupt service routine
ISR (WDT_vect) {
   wdt_disable();                       // disable watchdog
}

// ADC interrupt service routine
EMPTY_INTERRUPT (ADC_vect);             // nothing to be done here

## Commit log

2020-11-18 Update files
    [TinyDFPlayer_BOM_v1.0.tsv, TinyDFPlayer_BoardHolder.stl, TinyDFPlayer_SpeakerHolder_v2.stl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]
2022-09-09 Update BOM
    [TinyDFPlayer_BOM_v1.0.tsv]
